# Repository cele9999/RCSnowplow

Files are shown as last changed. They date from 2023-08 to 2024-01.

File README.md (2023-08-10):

# RC Snowplow
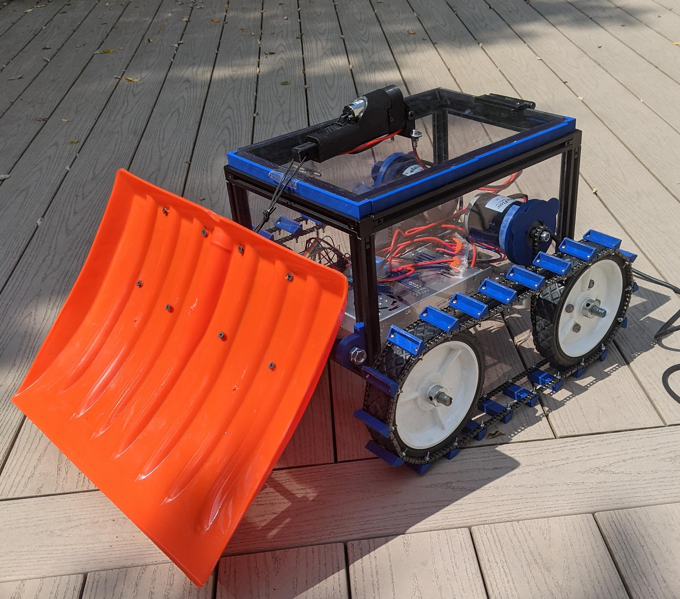
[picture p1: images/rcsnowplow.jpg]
RC Snowplow Logo

The SnowByte is an Open-Source Remote Controlled (RC) Snowplow that can help in clearing or removing snow from your driveway. Its a bare-bones RC vehicle that can be modified or customized using its code and supporting documentation. My goal was to put together a simple open-source Snowplow machine that people could build upon.

The frame was made using aluminum linear rails and 1/4" polycarbonate panels. Most of the electronics and mechanical parts are off-the-shelf, but it does require some 3D-printed parts and a few other components to complete the project. If you have worked with any hobby electronics for RC toys, and have access to some basic power tools, then you should have no problem building this project.

I would love to see your own creations of this project and maybe feature them here as well. Please email me at cele9999@gmail.com with any videos/pics of your RC creations. 

This code and 3D-print models are entirely free to use and will stay that way forever. If you found this helpful for your project, donations are appreciated: [Buy me a Pizza](https://bmc.link/cele9999)

# Patents, Local Laws, Liability

Before building a robot based on the designs published here, please make sure that you are allowed to do so in your specific regions. There may be patents and / or laws prohibiting you of doing so.

The code/schematics/PCB files are distributed in the hope that it will be useful, but WITHOUT ANY WARRANTY; without even the implied warranty of MERCHANTABILITY or FITNESS FOR A PARTICULAR PURPOSE.

This basically means: I'm just documenting a project of mine here for free and I don't have the time and resources to check that devices built using this information will be safe to use, legal to use or even work as intended. You will need technical know-how to use this project and I'm not liable for any damages your devices do to anyone or anything.

# License
<br />This work is licensed under a <a rel="license" href="http://creativecommons.org/licenses/by-nc-sa/4.0/">Creative Commons Attribution-NonCommercial-ShareAlike 4.0 International License</a>.

# Disclaimer
Before building a robot based on the designs published here, please make sure that you are allowed to do so in your specific regions. There may be patents and/or laws prohibiting you of doing so. The software/code/schematics/PCB/3D-Print files are distributed by the contributor “as is” in the hope that it will be useful, but WITHOUT ANY WARRANTY; without even the implied warranty of MERCHANTABILITY or FITNESS FOR A PARTICULAR PURPOSE. In no event shall the contributor be liable for any direct, indirect, incidental, special, exemplary, or consequential damages (including, but not limited to, procurement of substitute goods or services; loss of use, data, or profits; or business interruption).)This basically means: I'm just documenting a project of mine here for free and I don't have the time and resources to check that devices built using this information will be safe to use, legal to use or even work as intended. You will need technical know-how to use this project and I'm not liable for any damages your devices do to anyone or anything. Feel free to use the design in your private/educational projects, but don't try to sell the design or products based on it without getting my consent first. The idea here is to share knowledge, not to enable others to simply sell my work. Thank you for understanding.

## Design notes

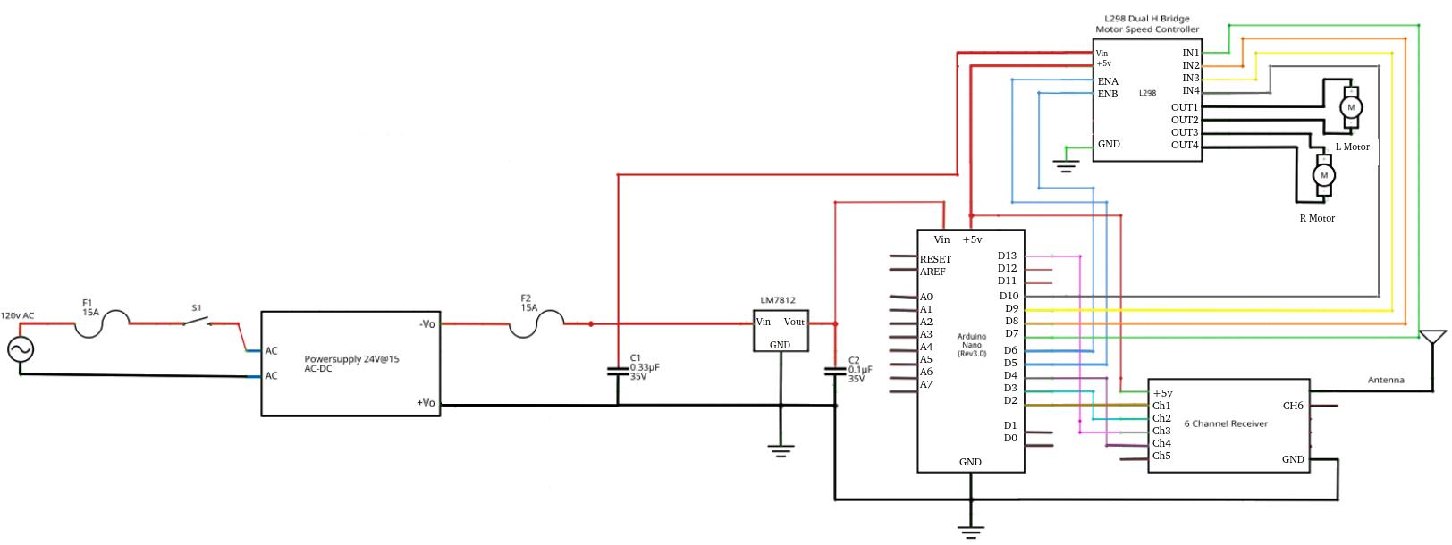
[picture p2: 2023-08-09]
images/schematic1.jpg

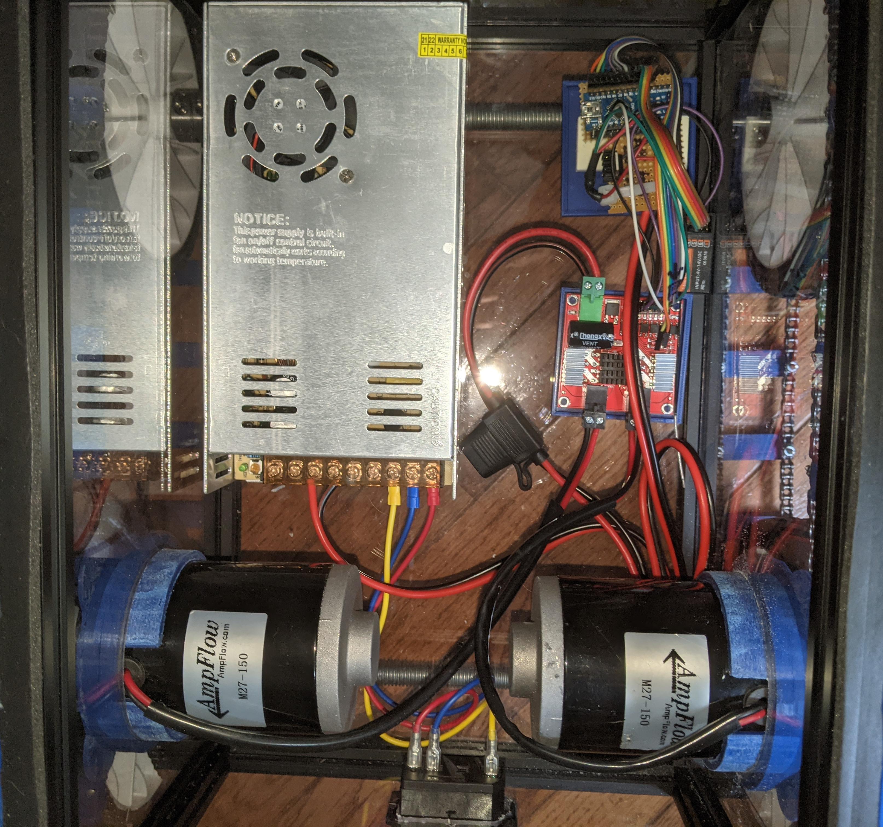
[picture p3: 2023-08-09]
images/electronics.jpg

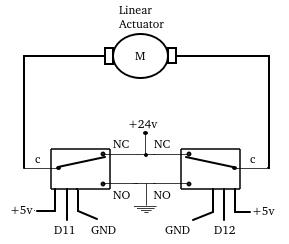
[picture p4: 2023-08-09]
images/schematic2.jpg

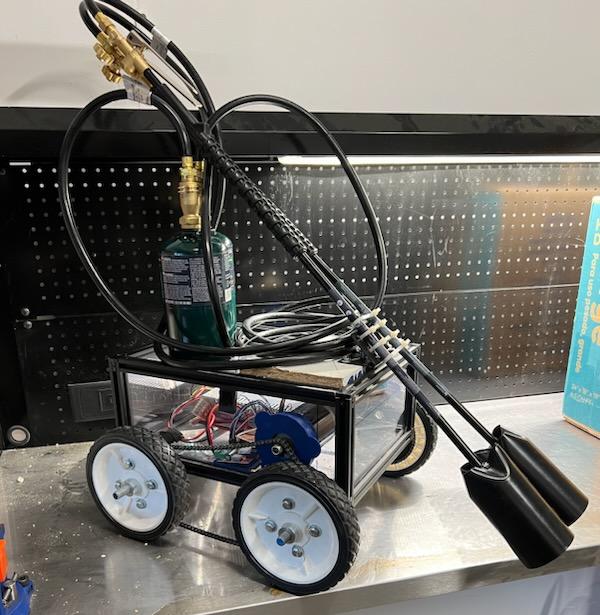
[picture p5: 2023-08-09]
images/rc-snowmelter1.jpg

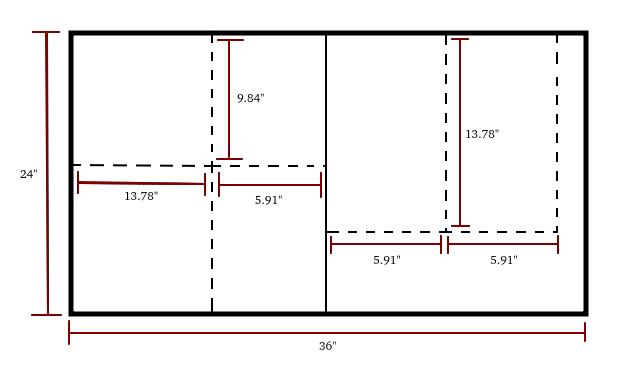
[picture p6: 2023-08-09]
images/polycarbonate-panels.jpg

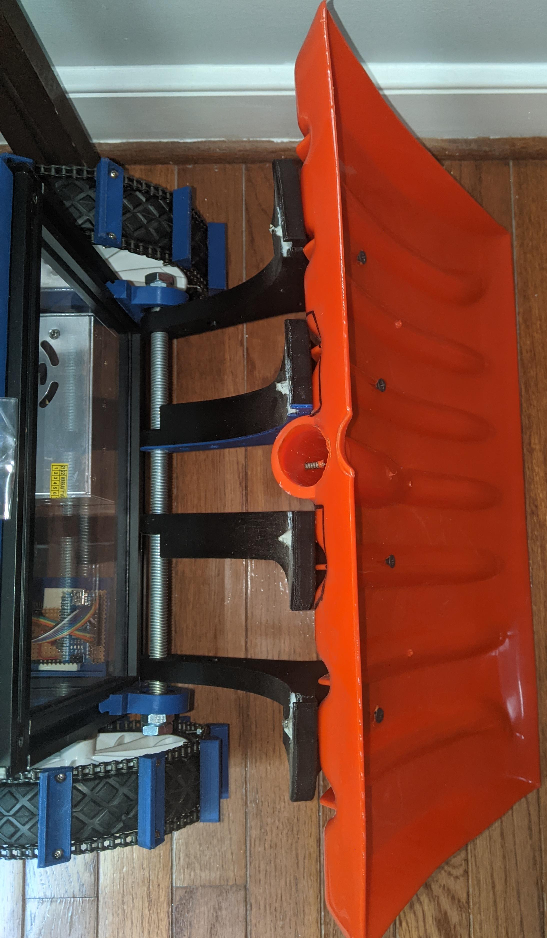
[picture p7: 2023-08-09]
images/snowplow-attachment2.jpg

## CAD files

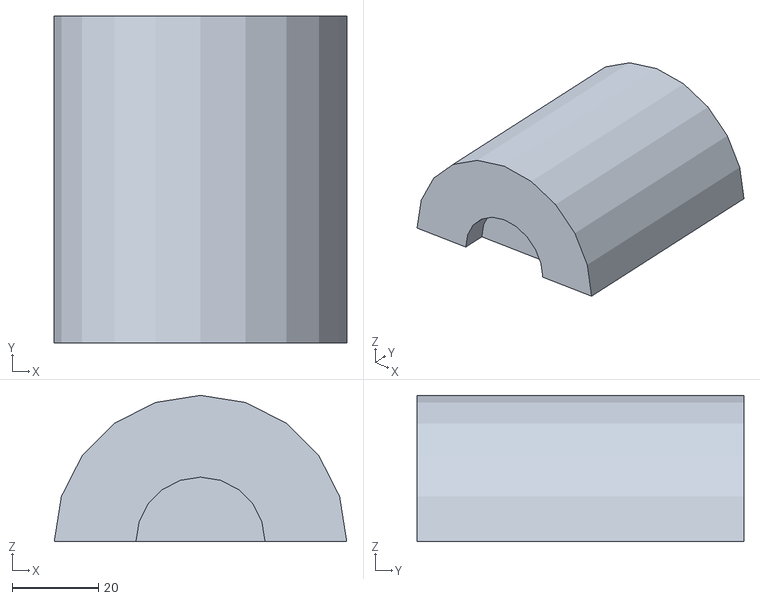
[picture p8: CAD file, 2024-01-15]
3d-print-files/motor-spacer-inner.stl
68.0 x 76.0 x 34.0

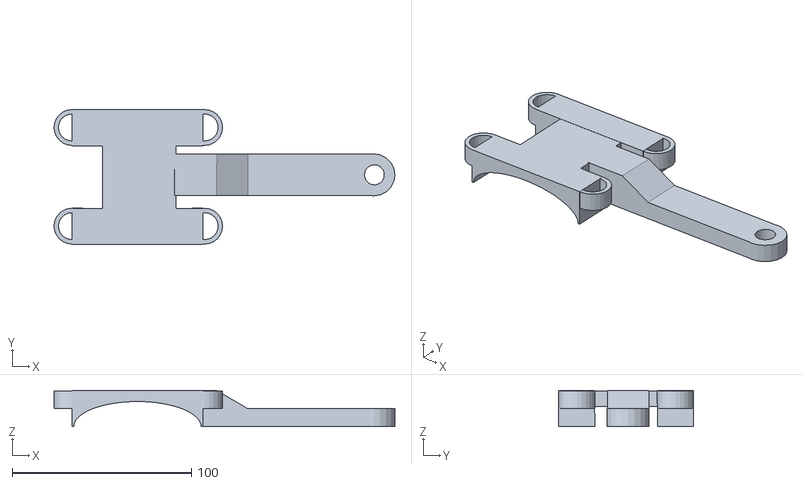
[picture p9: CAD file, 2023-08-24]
3d-print-files/trimmer-holder-arm.stl
190.1 x 75.2 x 20.2

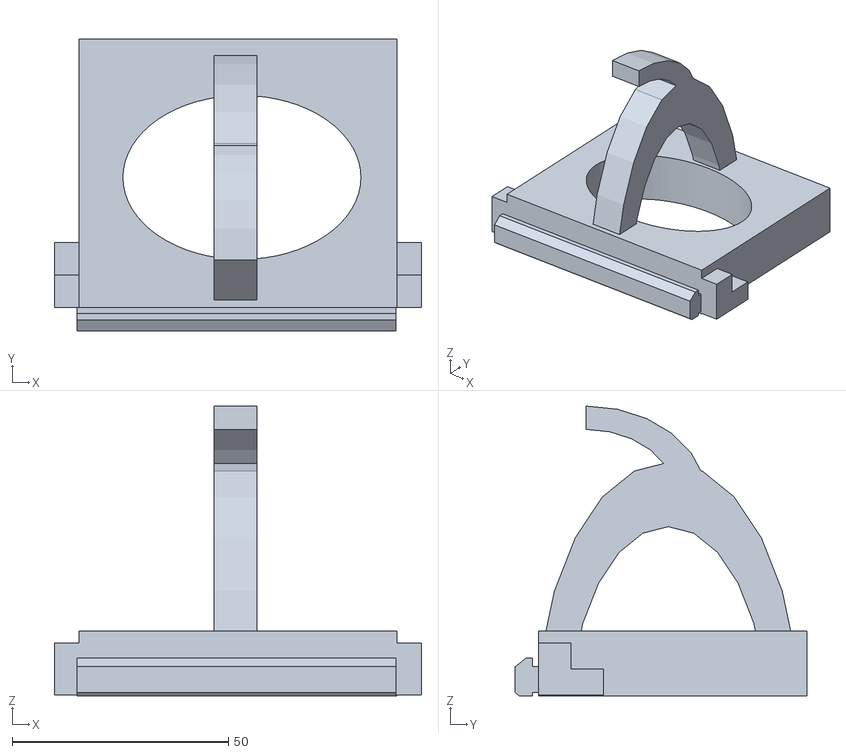
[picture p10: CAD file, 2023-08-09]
3d-print-files/cable-holder.stl
84.8 x 67.4 x 67.0

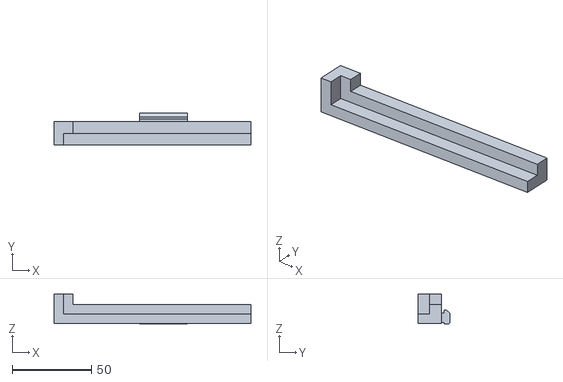
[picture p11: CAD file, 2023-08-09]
3d-print-files/lid-cover-frontface-half-l.stl
124.1 x 20.4 x 18.7

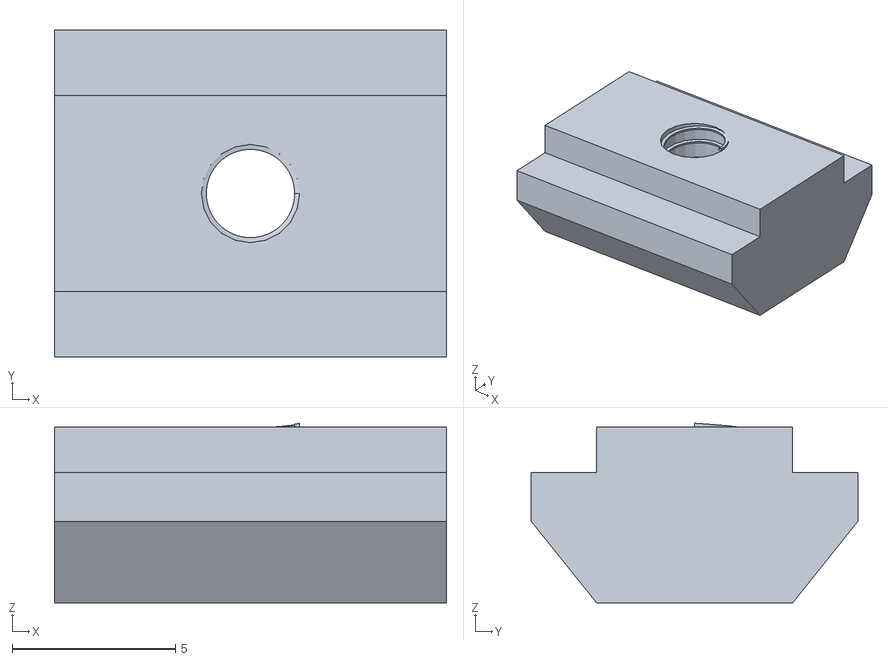
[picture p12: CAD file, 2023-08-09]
3d-print-files/rail-anchor-short.stl
12.0 x 10.0 x 5.50

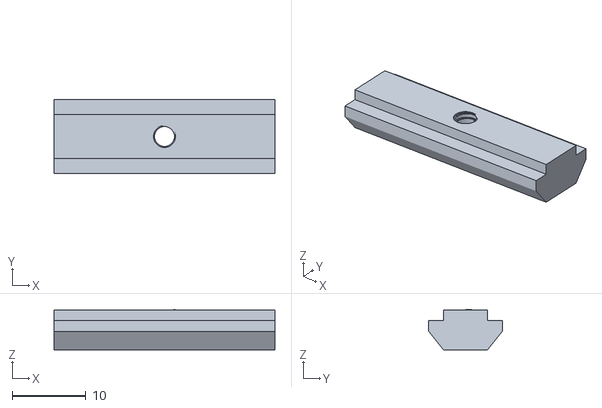
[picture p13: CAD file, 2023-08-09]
3d-print-files/rail-anchor-long.stl
30.0 x 10.0 x 5.50

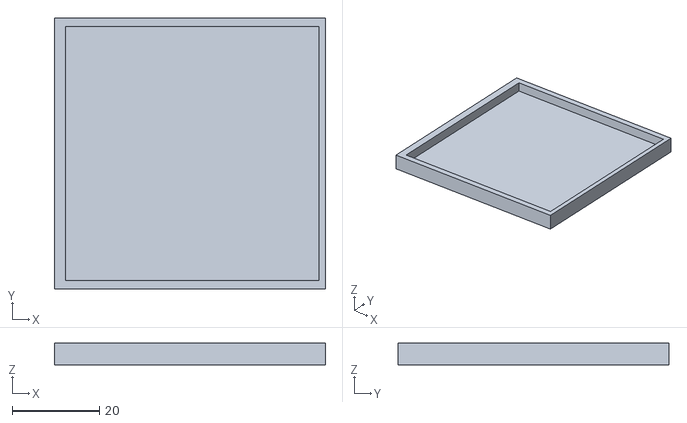
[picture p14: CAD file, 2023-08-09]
3d-print-files/driver-holder.stl
62.0 x 62.0 x 5.00

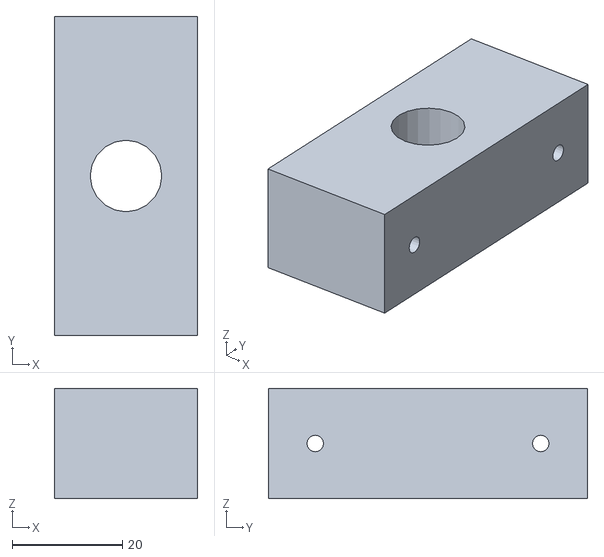
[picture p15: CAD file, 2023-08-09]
3d-print-files/axel-holder.stl
26.0 x 58.0 x 20.0

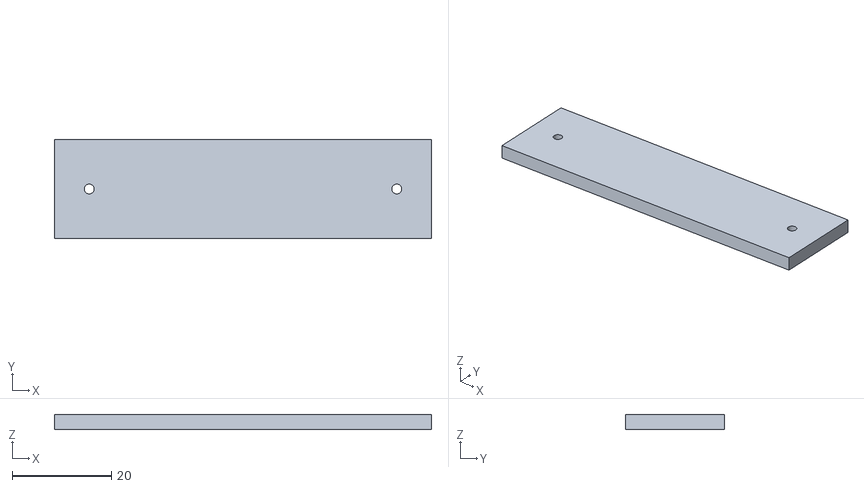
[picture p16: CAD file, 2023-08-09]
3d-print-files/lid-hinge-spacer.stl
76.0 x 20.0 x 3.00

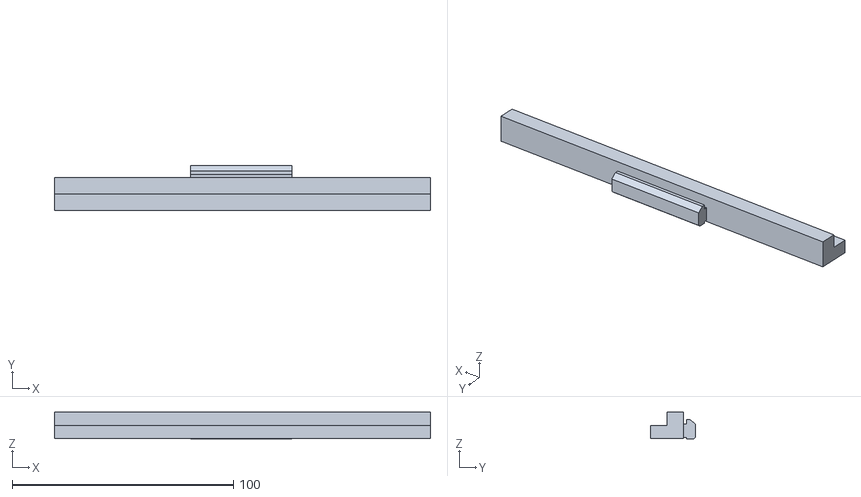
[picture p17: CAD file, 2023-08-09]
3d-print-files/lid-cover-side.stl
170.0 x 20.4 x 12.2

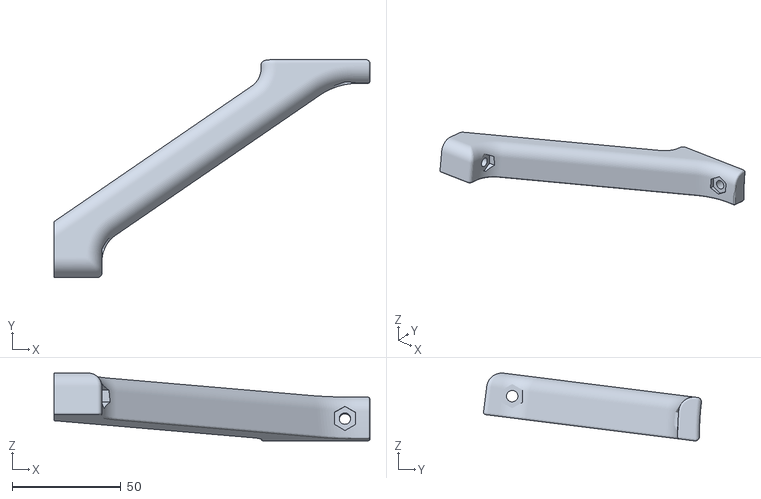
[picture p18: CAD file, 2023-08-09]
3d-print-files/Snow_Plow_holder-Part5.stl
145.0 x 100.0 x 31.2

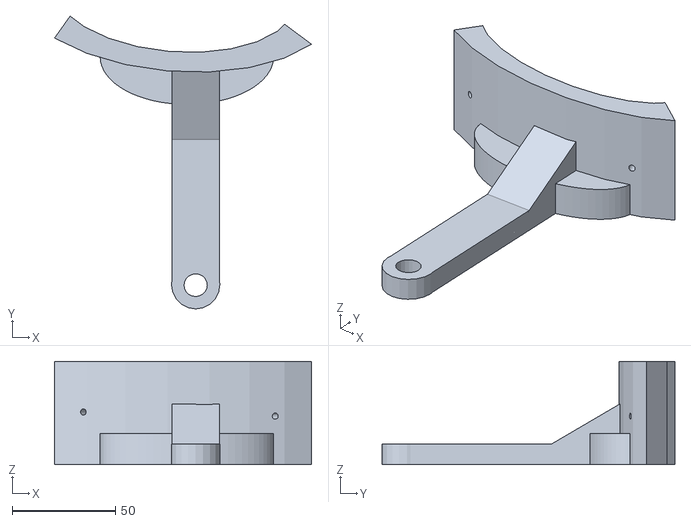
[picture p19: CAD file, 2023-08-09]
3d-print-files/plow-arm-r.stl
124.4 x 141.8 x 50.0

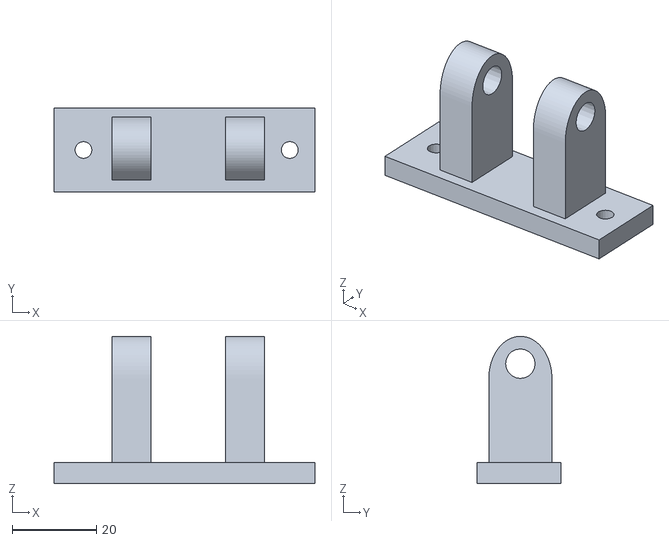
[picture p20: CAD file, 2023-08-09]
3d-print-files/actuator-holder.stl
62.0 x 20.0 x 35.0

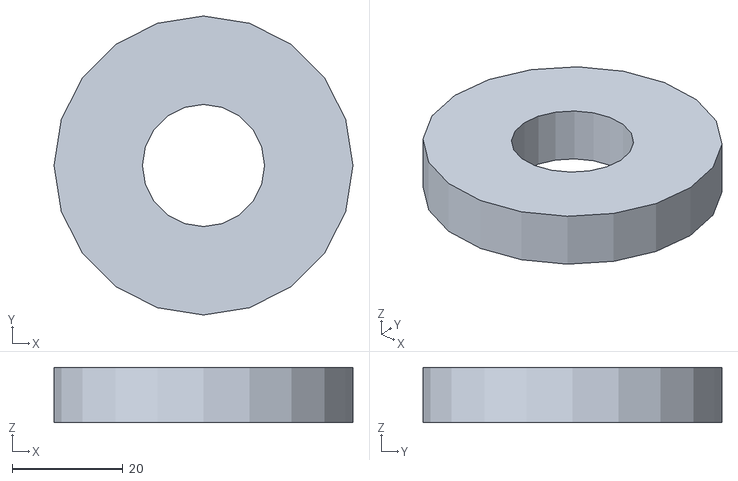
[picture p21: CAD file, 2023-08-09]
3d-print-files/gear-guide.stl
54.1 x 54.1 x 10.0

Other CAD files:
3d-print-files/lid-cover-frontface-half-r.stl
3d-print-files/plow-arm-l.stl
3d-print-files/motor-sleeve-spacer.stl
3d-print-files/motor-sleeve-v2.stl
3d-print-files/rail-holder.stl
3d-print-files/tank-thread.stl

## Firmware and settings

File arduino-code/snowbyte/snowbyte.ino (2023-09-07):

////////////////////////////
//Title: SnowByte         //
//Author: Gerardo Cruz    //
//Date: 1/14/23           //
//License: CC BY-NC-SA 4.0//
////////////////////////////

//Var Setup
bool control = 0;                            //Shows if controller has been detected since power up
int speed = 75;                              //Dictates initial speed of the motors. Value can be set between 0-255
int oldoption = 0;                           //Holds the last RC command
int option = 0;                              //Stores any new RC button presses
int sidectrl, fwdctrl, trimctrl, leverctrl;  //Stores RF Receiver values

//Arduino Variable  --> Arduino Pin --> TYPE   --> Description
//---------------------------------------------------------------
const int ch1 = 2;     // --> D2          --> INPUT  --> channel 1 of RF Receiver
const int ch2 = 3;     // --> D3          --> INPUT  --> channel 2 of RF Receiver
const int ch3 = 13;    // --> D13         --> INPUT  --> channel 3 of RF Receiver
const int ch4 = 4;     // --> D4          --> INPUT  --> channel 4 of RF Receiver
const int en1 = 5;     // --> D5          --> OUTPUT --> enable 1 of Motor Shield
const int en2 = 6;     // --> D6          --> OUTPUT --> enable 2 of Motor Shield
const int in1 = 7;     // --> D7          --> OUTPUT --> input 1 of Motor Shield
const int in2 = 8;     // --> D8          --> OUTPUT --> input 2 of Motor Shield
const int in3 = 9;     // --> D9          --> OUTPUT --> input 3 of Motor Shield
const int in4 = 10;    // --> D10        --> OUTPUT --> input 4 of Motor Shield
const int armup = 11;  // --> D11      --> OUTPUT --> Linear Actuator Up
const int armdn = 12;  // --> D12      --> OUTPUT --> Linear Actuator Down
const int trimmer = A0;// --> D14      --> OUTPUT --> Trimmer Motor On/Off
//Motor Speed Increasing Loop
void speedcontrol() {
  if ((oldoption == option) && (oldoption != 0) && (option != 0)) {
    if (speed < 256) {
      speed += 3;
      analogWrite(en1, speed);
      analogWrite(en2, speed);
    }
  } else {
    speed = 75;
    oldoption = option;
  }
}

//Setup Loop
void setup() {
  //ASSIGN PINS MODES AND VALUES
  Serial.begin(9600);
  pinMode(ch1, INPUT);
  pinMode(ch2, INPUT);
  pinMode(ch3, INPUT);
  pinMode(ch4, INPUT);
  pinMode(en1, OUTPUT);
  pinMode(en2, OUTPUT);
  pinMode(in1, OUTPUT);
  pinMode(in2, OUTPUT);
  pinMode(in3, OUTPUT);
  pinMode(in4, OUTPUT);
  pinMode(armup, OUTPUT);
  pinMode(armdn, OUTPUT);
  pinMode(trimmer, OUTPUT);
  digitalWrite(in1, LOW);
  digitalWrite(in2, LOW);
  digitalWrite(in3, LOW);
  digitalWrite(in4, LOW);
  digitalWrite(armup, LOW);
  digitalWrite(armdn, LOW);
  digitalWrite(trimmer, LOW);
  //ENABLE AND SET INITIAL MOTOR SPEED
  analogWrite(en1, speed);
  analogWrite(en2, speed);
}

//Main Loop
void loop() {
  //READ RF RECEIVER SIGNALS
  sidectrl = constrain(pulseIn(ch1, HIGH), 1000, 2000);
  fwdctrl = constrain(pulseIn(ch2, HIGH), 1000, 2000);
  trimctrl = constrain(pulseIn(ch3, HIGH), 1000, 2000);
  leverctrl = constrain(pulseIn(ch4, HIGH), 1000, 2000);
  Serial.println(sidectrl);
  Serial.println(fwdctrl);
  Serial.println(trimctrl);
  Serial.println(leverctrl);
  //WHEELS TURN LEFT/RIGHT OR NOT
  if (sidectrl == 1000 && fwdctrl == 1000 && leverctrl == 1000 && control == 0) {
    Serial.println("No controller detected");
  } else if (sidectrl <= 1600 && sidectrl >= 1400) {
    //WHEELS GO FORWARD/BACKWARDS OR NOT
    Serial.println("ch1=~1500");
    control = 1;
    if (fwdctrl <= 1600 && fwdctrl >= 1400) {
      Serial.println("ch2=~1500");
      option = 0;
      speedcontrol();
      analogWrite(in1, 0);
      analogWrite(in2, 0);
      analogWrite(in3, 0);
      analogWrite(in4, 0);
    } else if (fwdctrl > 1600) {
      Serial.println("ch2=~2000");
      option = 22;
      speedcontrol();
      analogWrite(in1, 0);
      analogWrite(in2, map(fwdctrl, 1600, 2000, 51, 255));
      analogWrite(in3, 0);
      analogWrite(in4, map(fwdctrl, 1600, 2000, 51, 255));
    } else if (fwdctrl < 1400) {
      Serial.println("ch2=~1000");
      option = 21;
      speedcontrol();
      analogWrite(in1, map(fwdctrl, 1400, 1000, 51, 255));
      analogWrite(in2, 0);
      analogWrite(in3, map(fwdctrl, 1400, 1000, 51, 255));
      analogWrite(in4, 0);
    } else {
      Serial.println("ch2=~1500-last");
      option = 0;
      speedcontrol();
      analogWrite(in1, 0);
      analogWrite(in2, 0);
      analogWrite(in3, 0);
      analogWrite(in4, 0);
    }
  } else if (sidectrl > 1600) {
    Serial.println("ch1=~2000");
    control = 1;
    option = 12;
    speedcontrol();
    analogWrite(in1, 0);
    analogWrite(in2, map(sidectrl, 1600, 2000, 51, 255));
    analogWrite(in3, map(sidectrl, 1600, 2000, 51, 255));
    analogWrite(in4, 0);
  } else if (sidectrl < 1400) {
    Serial.println("ch1=~1000");
    control = 1;
    option = 11;
    speedcontrol();
    analogWrite(in1, map(sidectrl, 1400, 1000, 51, 255));
    analogWrite(in2, 0);
    analogWrite(in3, 0);
    analogWrite(in4, map(sidectrl, 1400, 1000, 51, 255));
  }
  //LEVER UP/DOWN
  if (sidectrl == 1000 && fwdctrl == 1000 && leverctrl == 1000 && control == 0) {
    Serial.println("No controller detected");
  } else if (leverctrl <= 1600 && leverctrl >= 1400) {
    Serial.println("ch4=~1500");
    control = 1;
    digitalWrite(armup, LOW);
    digitalWrite(armdn, LOW);
  } else if (leverctrl > 1600) {
    Serial.println("ch4=~2000");
    control = 1;
    digitalWrite(armup, HIGH);
    digitalWrite(armdn, LOW);
  } else if (leverctrl < 1400) {
    Serial.println("ch4=~1000");
    control = 1;
    digitalWrite(armup, LOW);
    digitalWrite(armdn, HIGH);
  } else {
    Serial.println("ch4=~1500-last");
    control = 1;
    digitalWrite(armup, LOW);
    digitalWrite(armdn, LOW);
  }
  //TRIMMER ON/OFF
   if (sidectrl == 1000 && fwdctrl == 1000 && trimctrl == 1000 && leverctrl == 1000 && control == 0) {
    Serial.println("No controller detected");
  } else if (trimctrl >= 1600) {
    //TRIMMER ON
    Serial.println("ch3=~2000");
    control = 1;
    digitalWrite(trimmer, HIGH);
    //TRIMMER OFF
  } else {
    Serial.println("ch3=~1000");
    digitalWrite(trimmer, LOW);
  }

  delay(50);
}

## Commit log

2023-08-09 Uploaded code and 3d-printed files
    [Snow_Plow_holder-Part5.stl, actuator-holder.stl, axel-holder.stl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]
2023-08-24 Added trimmer-holder-arm.stl
    [trimmer-holder-arm.stl]
2024-01-15 added inner motor spacer
    [motor-spacer-inner.stl]
